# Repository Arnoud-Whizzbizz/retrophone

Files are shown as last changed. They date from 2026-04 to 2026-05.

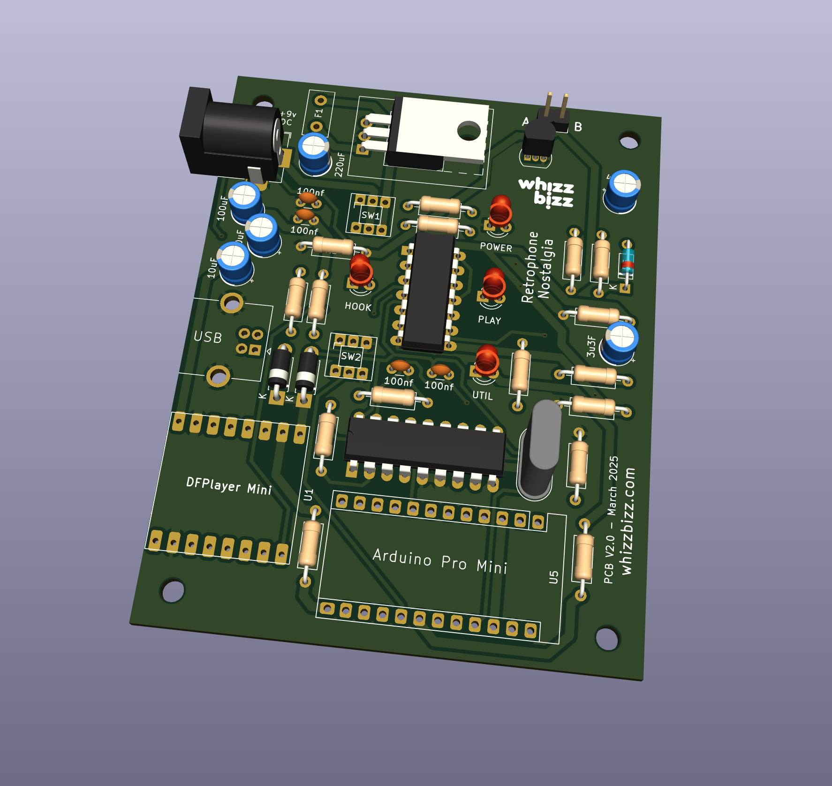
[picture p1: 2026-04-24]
Printed circuit board/pcb-render.png

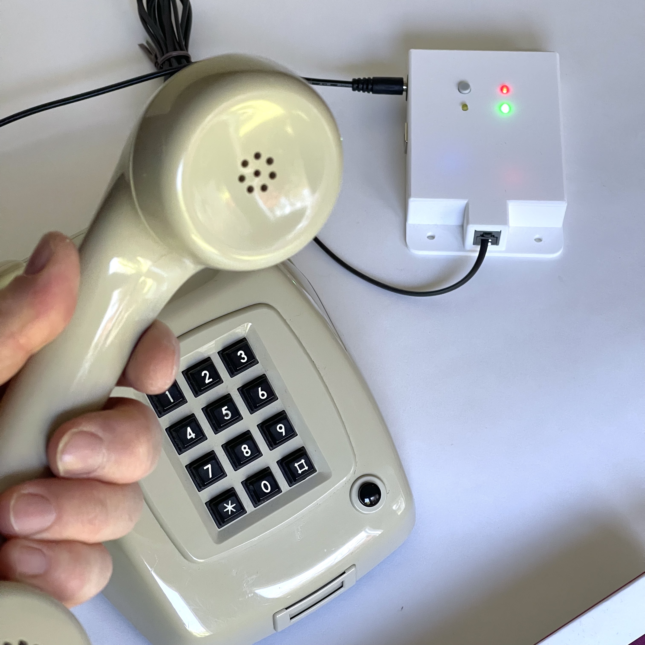
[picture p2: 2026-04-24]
Images/vintage-tone-dial-RJ11.jpeg

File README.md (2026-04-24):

the Retrophone! Use any modern or vintage telephone to play MP3s!!

This is a box that can be supplied in various versions. Any classic or modern telephone can be connected to it. The basic model is 'open-source'. The schematic, the software, the design of the printed circuit board and the 3D design of the box can be used by anyone with some technical knowledge to build one themselves. This switchboard can be used with dial telephones as well as with the more modern push-button (DTMF, such as the T65 TDK) telephones.

Just plug in your phone and you're done. A hundred of different music or audio fragments can be played with it. The phone actually waits for the dialing of a complete phone number and bases on which fragment is played.

Getting started and manual on https://www.whizzbizz.com/en/mp3-player-switchboard
DIY building instructions on https://www.whizzbizz.com/en/retro-phone-mp3-player
More about FTDI programming: https://www.whizzbizz.com/en/retrophone-ftdi-programming

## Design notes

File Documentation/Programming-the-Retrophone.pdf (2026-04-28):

Programming the Retrophone – [v1.2 april 2026]

Programming the microcontroller

The Retrophone is built around a microcontroller (Arduino Pro Mini, 5 volts, 16 MHz). In addition to the schematic, the 3D design of the enclosure, and the PCB layout, the firmware is also open-source and can be found on the project page for the design on GitHub.

GitHub: https://github.com/Arnoud-Whizzbizz/retrophone

Anyone who has built the Retrophone themselves will first need to install the firmware—the program stored in the microcontroller—before the circuit can be put into use. However, anyone who wishes to modify the existing functionality and has sufficient technical knowledge can also (re)program the Retrophone. For software development, the Arduino IDE development environment is the obvious choice. It can be downloaded for free from the official Arduino website.

Arduino IDE: https://docs.arduino.cc/software/ide/

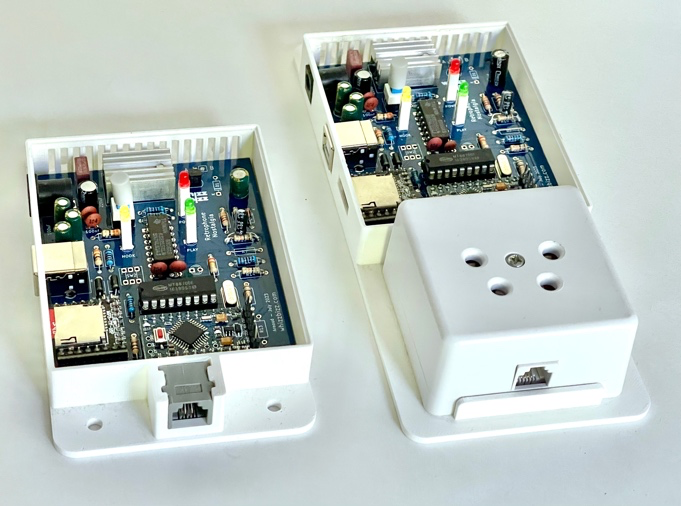
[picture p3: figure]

To program or reprogram the Arduino Pro Mini, you must open the case and connect a suitable programmer with a USB connection to the six exposed pins on the short side of the microcontroller board. A so-called FTDI programmer is used for this purpose, and various inexpensive versions are available for purchase online. The photos below show two versions with an FT232RL FTDI chip.

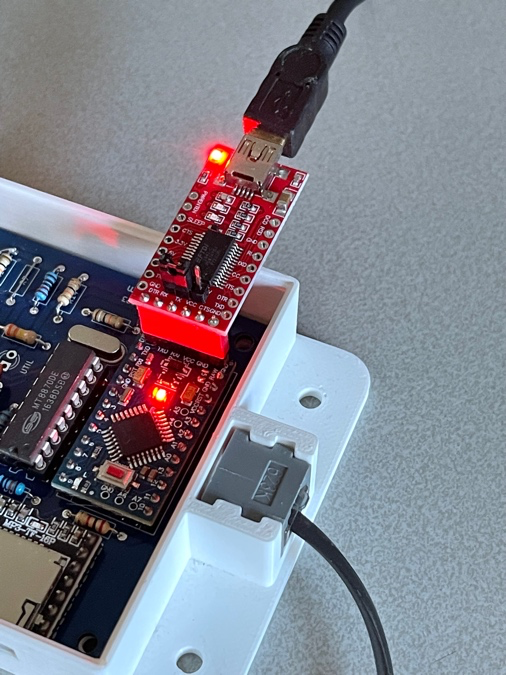
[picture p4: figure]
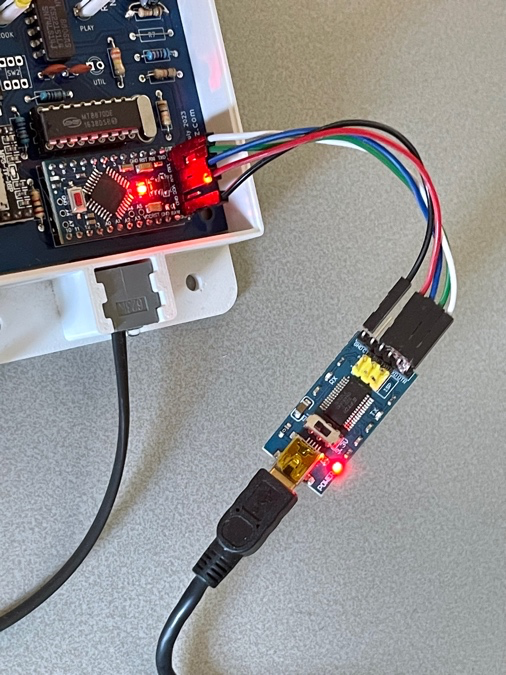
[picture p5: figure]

As soon as the FTDI board is connected, it will appear on your computer as a USB interface, and the software loaded or developed in the Arduino IDE can be uploaded to the Retrophone’s microcontroller.

A detailed description of programming the ATmega328P chip in the Arduino Pro Mini is, of course, beyond the scope of this document. Fortunately, there is a wealth of information available online about
programming an Arduino microcontroller using the Arduino IDE.

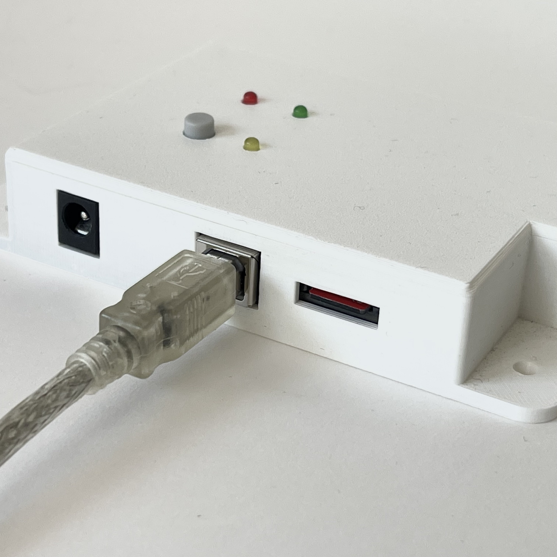
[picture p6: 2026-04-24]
Images/USB-B-connection.jpeg

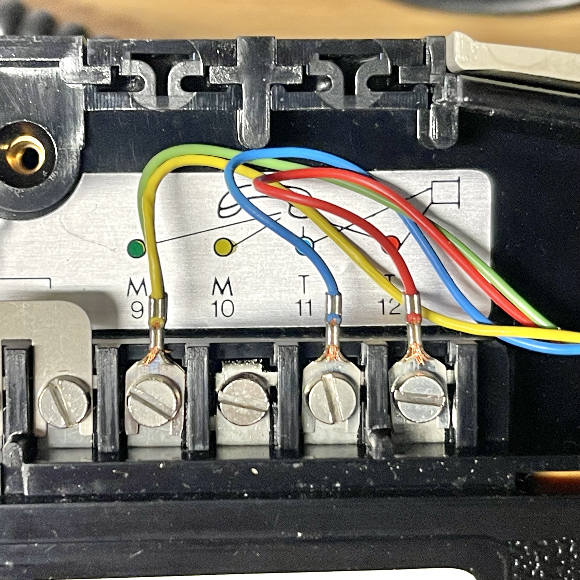
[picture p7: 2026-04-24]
Images/combine-9-and-10.jpeg

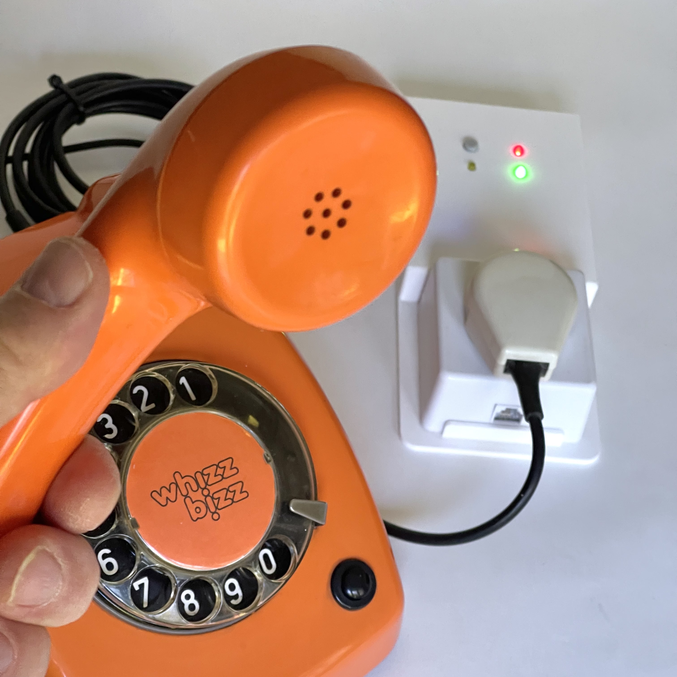
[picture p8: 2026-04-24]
Images/vintage-rotary-dial-PTT.jpeg

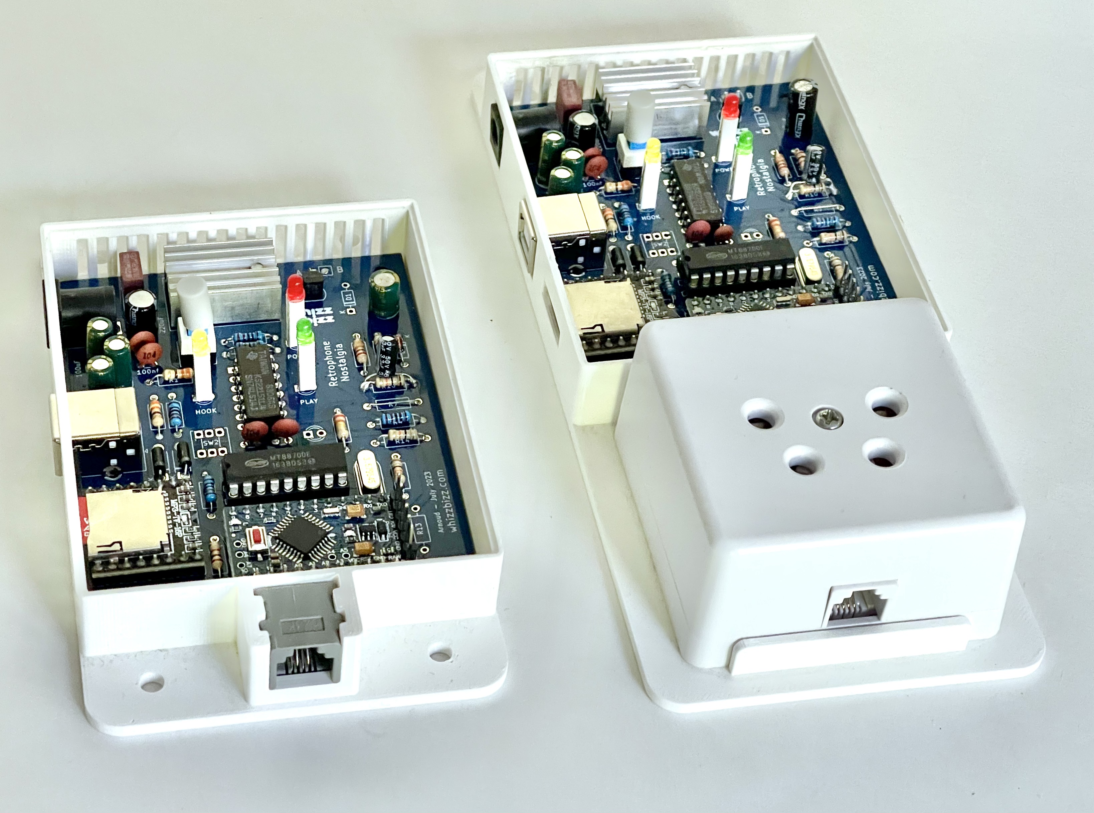
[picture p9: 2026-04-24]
Images/both-models.jpeg

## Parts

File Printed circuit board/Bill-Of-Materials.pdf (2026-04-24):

Bill of materials IDK+(TDK) 'Retrophone' Rev1 (july 2023) & Rev2 (march 2025) - Arnoud Whizzbizz.com

Designator | Package | Quantity Designation | Comment, Link
R12,R5 | Axial DIN0207 L6.3mm P10.16mm | 2 | 1K
R3 | Axial DIN0207 L6.3mm P10.16mm | 1 | 330
R17,R16,R8 | Axial DIN0207 L6.3mm P10.16mm | 3 | 2K2
D3,D8,D7,D6 | LED_D3.0mm | 4 | LED 3mm
U5 | Arduino_Pro_Mini | 1 | Pro Mini 328 | 35 pin Arduino Pro Mini module with FTDI programming port
SW1 | SW_Push_2P2T_7x7 | 1 | POWER | 7x7mm DPDT with lock - Take care of mounting orientation!
U1 | DFPlayer_Mini | 1 | DFPlayerMini | DFPlayer Mini module. Use MP3-TF-16P with the blue LED!
CP2,CP1 | CP_Radial_D5.0mm_P2.50mm | 2 | 10uF
C3,C5 | C_Disc_D3.0mm_W1.6mm_P2.50mm | 4 | 100nf
F1 | Fuse_8.5x4 | 1 | 500mA
U3 | TO-220-3_Horizontal_TabUp_Heatsink | 1 | LM7805_TO220 | LM7805 with alu heatsink 22x15 mm, 10mm high for TO-220 package
Q1 | TO-92_Inline | 1 | BC547
C2 | CP_Radial_D5.0mm_P2.50mm | 1 | 220uF
U2 | DIP-14_W7.62mm_LongPads | 1 | 74LS14 | DIP14 TTL Hex Schmitt Trigger Inverters
D2,D4 | D_DO-41_SOD81_P7.62mm_Horizontal | 2 | 1N5817 | Schottky diodes
C7 | CP_Radial_D5.0mm_P2.50mm | 1 | 470uF
C8 | CP_Radial_D5.0mm_P2.50mm | 1 | 3u3F
C4 | CP_Radial_D5.0mm_P2.50mm | 1 | 100uF
R10 | Axial DIN0207 L6.3mm P10.16mm | 1 | 10K
R14,R15 | Axial DIN0207 L6.3mm P10.16mm | 2 | 10K
R2 | Axial DIN0207 L6.3mm P10.16mm | 1 | 27K
R4 | Axial DIN0207 L6.3mm P10.16mm | 1 | 2K2
R1 | Axial DIN0207 L6.3mm P10.16mm | 1 | 330
D5 | D_DO-35_SOD27_P7.62mm_Horizontal | 1 | 1N4148 | Rotated cathode designator on silk screen of pcb Rev1! Rotate 180 degrees!
J1 | BarrelJack_Horizontal | 1 | Barrel_Jack_Switch | DC input for 9v adaptor (5.5mm with 2.5mm pin)
J3 | PinHeader_1x02_P2.54mm_Vertical | 1 | Phone | 2-pin header for connecting a/b of the phone connector
D1 | D_DO-35_SOD27_P7.62mm_Horizontal | 1 | 1N4001 | Rotated cathode designator on silk screen of pcb Rev1! Rotate 180 degrees!
J2 | USB_B_OST_USB-B1HSxx_Horizontal | 1 | USB_B | USB-B type pcb connector (optional)
R7 | Wire bridge (Resitor has been removed) | 1 | Wire | Only on pcb Rev1 (july 2023), was corrected in pcb Rev2 (march 2025)

Optional momentary-action switch SW2 Util/Config button with LED D6
Designator | Package | Quantity Designation | Comment, Link
SW2 | SW_Push_2P2T_7x7 | 1 | UTIL/CONFIG | 7x7mm DPDT without lock - Take care of mounting orientation!
R13 | Axial DIN0207 L6.3mm P10.16mm | 4 | 2K2
D6 | LED_D3.0mm | 4 | LED 3mm | Util/Config LED

Optional DTMF ('TDK') decoding (tone dialing and modern phones)
Designator | Package | Quantity Designation | Comment, Link
Y1 | Crystal_HC18-U_Vertical | 1 | 3.579545 MHz | May be classic high model, or low passive resonator model
U4 | DIP-18_W7.62mm | 1 | MT8870 | DIP18 version of the MT8870 or MV8870 DTMF decoder
C1, C6 | C_Disc_D3.0mm_W1.6mm_P2.50mm | 4 | 100nf
R6, R9 | Axial DIN0207 L6.3mm P10.16mm | 2 | 100K
R11 | Axial DIN0207 L6.3mm P10.16mm | 1 | 330K

Casing, 3D-prints, additional assembly materials
Designator | Package | Quantity Designation | Comment, Link
PCB | Printed Circuit Board | 1 | Rev1 or Rev2 | Printed Circuit Board (Gerber files on GitHub)
3DCASE | 3D printed case (either for RJ11 or Dutch PTT connector) | 1 | | STL files of (wall-)case and lid on GitHub
HTSNK | Heatsink for TO-220 | 1 | | Aluminum heatsink 22x15 mm, 10mm high for TO-220
SPACER | Aluminum washer spacer | 1 | 4mm thick | Used for mounting the heatsink and 7805 regulator
SCREW1 | M3 bolt | 2 | M3 x 12mm | M3 bolt for fixing the heatsink and 7805 regulator
WASH1 | M3 washer | 2 | | Steel washer M3 to assemble heatsink and 7805 regulator
SDCARD | SD-Card for the DFPlayer Mini | 1 | | >=2GB is recommended
BTNCAP | Tactile Push Button Switch Cap 10mm | 2 | | Tactile Push Button Switch Cap 10mm
SCREW2 | 3 x 12mm Countersunk head screw | 4 | | Used to fix the lid and secure the pcb in the case
SCREW3 | M3 Bolt | 2 | M3 x 12mm | M3 bolt for fixing the classic Dutch PTT phone wall box
WASH2 | M3 Washer | 2 | M3 | Steel washer M3 to firmly assemble the wall box
M3NUT | M3 Nut | 2 | M3 | DIN934 M3 Hex Nut Metric Thread
WIRE | Small length of colored (red/blue) electric wire | 2 | 100mm | General purpose 24 AWG electric wire for connecting a/b of phone
PHONE CONN | Landline wall box for connecting a Dutch PTT phone | 1 | | Dutch: Q-Link telefoon contactdoos opbouw (Art.Nr. 00.133.44)
| OR: Wired 6P4C RJ11/12 chassis connector female | 1 | | Use only green and red wires to connect to 'A' and 'B' inputs
POWER | AC/DC 9V 2A Switching Power Supply Adapter | 1 | | AC/DC 9V 2A Switching Power Supply Adapter
| IDK "Impuls Druk kiezen": Pulses during the dialing
| TDK "Toon Druktoets Keuze": Tones during the dialing

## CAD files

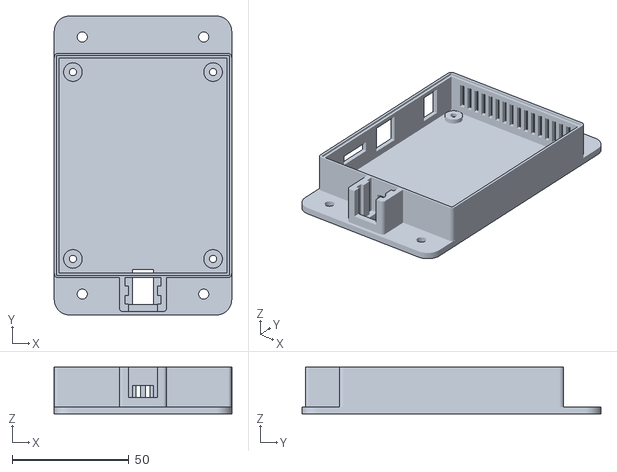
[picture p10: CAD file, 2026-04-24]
3D/RJ11-port-case.stl
76.0 x 128.0 x 20.0

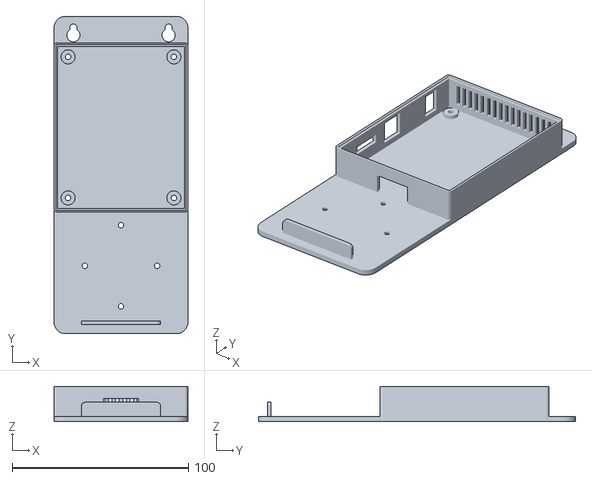
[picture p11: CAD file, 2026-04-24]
3D/wall-case.stl
76.0 x 180.0 x 20.0

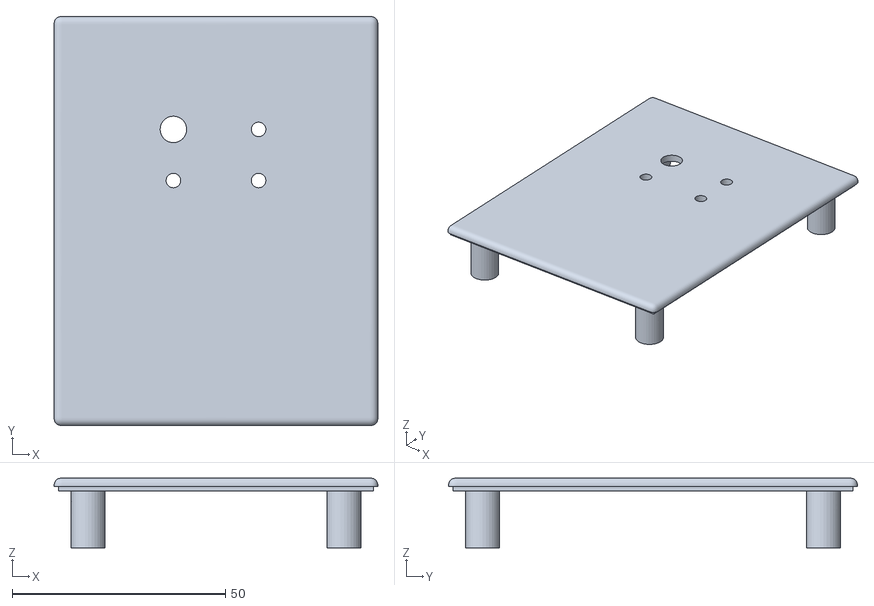
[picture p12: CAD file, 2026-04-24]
3D/lid-flat-basic-holes.stl
76.0 x 96.0 x 16.4

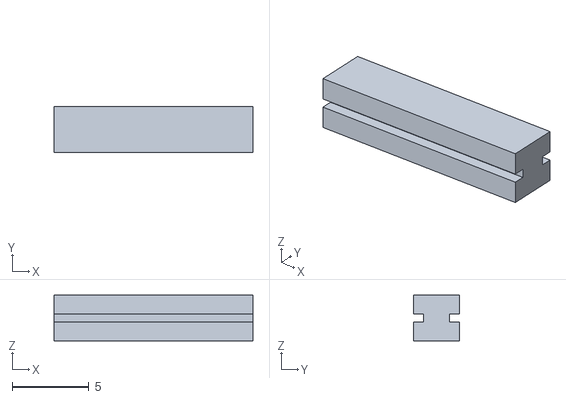
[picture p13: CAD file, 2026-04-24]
3D/LED_raiser.stl
13.0 x 3.00 x 3.00

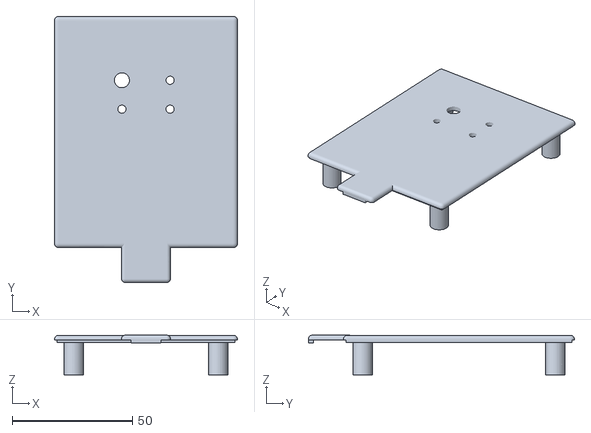
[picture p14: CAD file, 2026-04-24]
3D/lid-flat-basic-holes-RJ11-lip.stl
76.0 x 110.5 x 16.4

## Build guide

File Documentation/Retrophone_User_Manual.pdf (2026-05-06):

Retrophone User Manual – [v1.2 april 2026]

What is the Retrophone?

The Retrophone is a “telephone switchboard” to which you can connect a classic “landline” telephone. When you pick up the receiver, you will hear a dial tone. After dialing a phone number, one of the hundred audio clips on the memory card will play. With the dialed numbers, any of the up to ten audio clips in up to ten folders on the memory card can be played.

No modifications are required for the phone to be used. Depending on the Retrophone model, rotary-dial phones (IDK) and/or push-button phones (TDK) can be used. Depending on the version, a classic phone can be connected using the traditional Dutch PTT plug, while a modern phone can be connected using a modular RJ11 plug.

Get started

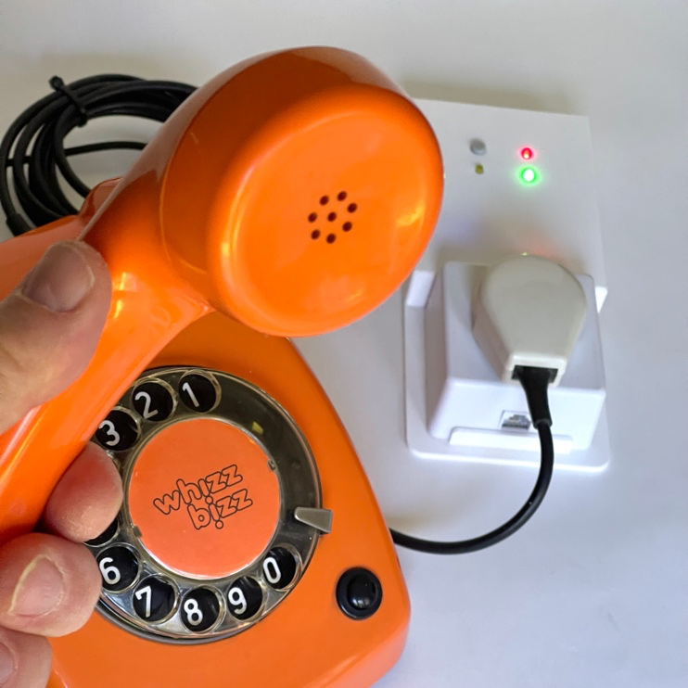
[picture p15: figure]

The Retrophone is powered by a 9-volt DC power adapter. Only models with a 5.5 mm pin diameter and a 2.5 mm hole (for the positive terminal) can be used. If the power adapter is not included, please check that your power adapter is compatible before using it! The technical specifications are listed on the back of the Retrophone.

The power adapter is connected to the side of the Retrophone. Here you will also find (optionally) the USB port for accessing the memory card, and a slot for removing the memory card. Detailed information about the memory card’s file structure can be found later in this manual.

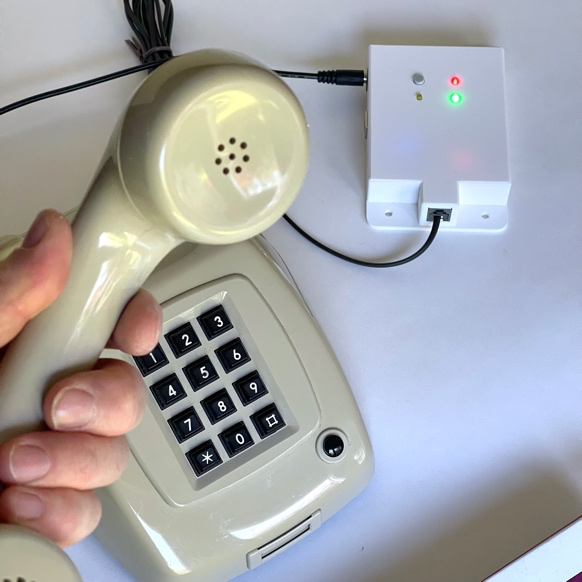
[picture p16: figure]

Turning on the Retrophone

Once the power adapter and phone are connected, and a microSD memory card is inserted, the Retrophone can be turned on using the power switch on the front.

The colored lights (LEDs) will all light up simultaneously for a moment. When only the red light next to the power switch is lit, the Retrophone is ready for use.

Preparing the memory card

The Retrophone includes an audio player (MP3-TF-16P, also known as the DFPlayer Mini) that allows audio files to be played directly from a microSD card (also known as a TF card). This memory card must be formatted with the MS-DOS or ExFAT file system. Memory cards with a maximum storage capacity of 32 GB can be used. However, for most applications, microSD cards with a smaller storage capacity (e.g., 8 GB) are usually more than sufficient.

File organization and playback principles

The file format and naming convention for the audio files on the memory card are straightforward. In addition to a few audio files at the root level, the memory card may contain up to ten numbered folders (“01”, “02”, “03” … through “10”). Each folder may contain up to 10 audio clips. Since the player isn’t very sophisticated, it’s advisable to use numbered filenames for these clips as well (‘001.WAV’, ‘002.WAV’ … through 010.WAV). This way, the folders can hold up to 100 audio clips.

From the root directory of the microSD card, only the first two audio files found are used. The first is played when the phone’s receiver is picked up. This is usually the dial tone that should be heard in the receiver while dialing the phone number, though it can also be a spoken instruction or similar. The second audio clip, usually the “busy tone,” is played if, based on the dialed phone number, no audio clip can be found. In principle, this is only possible if there are fewer than 100 playable clips in the folders on the microSD card.

The link between the phone number dialed by the user on the connected phone and the audio clip that is ultimately played is very simple: the very first digit dialed determines the folder (1 for folder ‘01’, 2 for folder ‘02’, etc.), and the very last digit dialed in the sequence determines the audio clip to be played within that folder (1 for ‘001. WAV’, 2 for ‘002.WAV’, etc.). If only one number is dialed within the maximum sequence number timeout (2.5 sec.) of the dialing phase, this is the clip number in the first folder ‘01’.

Audio encoding of the audio files

In principle, the Retrophone’s player can play audio files in WMV/WMA (WAV) and MP3 formats. When encoding to MP3, a ‘constant bitrate’ (CBR) of 128 kbps gives the best results. However, in practice, MP3 files in the numbered folders are sometimes not recognised properly. The dial tone and busy tone, the files for which are stored on the root level of the memory card, cause fewer problems in this regard.

The WMV/WMA audio format is compressed and requires decompression during playback by the audio player. As these are often short clips in practice, it is recommended to choose the most standardised (uncompressed) WAV variant. Although this results in slightly larger audio files, they offer significantly better playback quality. Encode the files at a maximum of 32 kHz, 16-bit in mono (stereo is, of course, pointless for this application) for the best results. Theoretically, sampling rates of 44.1 kHz and even 48 kHz at 24-bit resolution are possible, but the resulting improvement in quality is far beyond the technical capabilities of a mobile phone speaker.

The best audio converters for both Windows and Mac are fre:ac (free and open-source), MediaHuman Audio Converter (free, user-friendly), and Switch Audio Converter (paid, but very versatile). These programs support formats such as MP3, WAV, FLAC, and M4A, and offer batch conversion, making it easy to convert multiple files to a different audio format all at once.

Accessing the files on the memory card using your computer

To back up the current contents of the memory card or load a completely new set of audio clips, you must first make the memory card accessible in your computer’s file explorer (Windows: File Explorer, Mac: Finder). To do this, first turn off the Retrophone using the power button on the front panel. You can also unplug the 9-volt AC adapter. Make sure the red LED is off.

To access the files on the memory card using your computer, we
recommend removing the memory card from the Retrophone’s slot. To

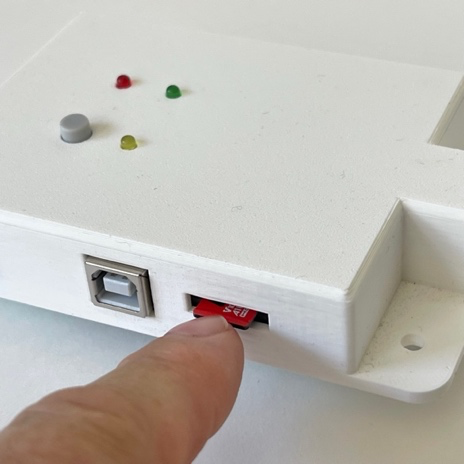
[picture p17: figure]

do this, gently push the SD card slightly further into the slot from the side of the case. When you release the card, a spring mechanism will cause it to pop out slightly, making it easy to remove from the slot. Some computers have a slot where the microSD card can be inserted directly. However, it is also always possible to temporarily place the memory card in a card adapter—such as a card reader that looks like a USB flash drive or a larger SD card—to make it accessible on your computer. When you are finished, you can carefully push the memory card back into the slot. The Retrophone is then ready for use again.

If your Retrophone has a square USB-B port (this does not apply to all
models), you can use a USB-A (standard flat plug) to USB-B (square) cable
to connect the Retrophone to your computer. The advantage of this is that
you don’t need to use a microSD card adapter, but keep in mind that this connection isn’t as fast as the one described above. And remember that when you’re done and want to use the Retrophone again, you’ll need to disconnect the USB cable. As long as the microSD card is “claimed” by your computer, the Retrophone cannot play audio files from it!

Edit or add audio clips to the memory card

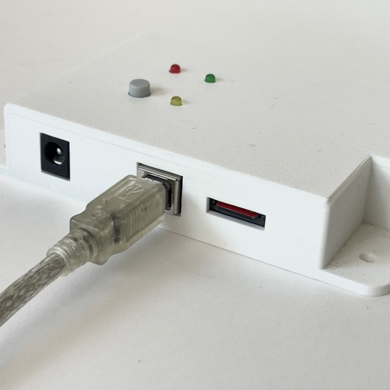
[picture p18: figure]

The Retrophone’s audio player has very limited “intelligence.” The player selects tracks based entirely on the order of the files on the microSD card. The (sequentially numbered) file names, which can be used on your computer to sort the files in a specific order, are ignored! Only the order in which the files were written from your computer to the microSD card determines the sequence number assigned by the player.

This is important to understand, because it explains why it is not possible to renumber files later in the naming scheme, or to insert files into the naming sequence on the memory card. These additional files will simply be written physically after the files already present on the memory card, regardless of the visible order based on their filenames. The underlying physical order on the microSD card will therefore differ from the folder view on your computer in those cases!

It is therefore advisable to set up (and manage and archive) the desired final file structure of the memory card in a folder on your computer’s hard drive. If you acquire a ready-made Retrophone that includes a memory card, you should make a complete copy of this memory card. In a separate folder (possibly cloned from the original), you can then create your own set of audio clips, copying the folder structure (and, if applicable, the dial tone and busy tone). By managing the various memory card “contents” on your computer, you can easily switch between the different collections of clips for various applications of the Retrophone.

Copying a new set of audio clips to the memory card

Once the new set of audio clips has been compiled on the computer, it can be written to an empty microSD card in one go.

Note: If you are using a Mac, “hidden” files will have been written to the microSD card that may confuse the player. It is important that these hidden “AppleDouble” metadata files (.DS_Store, etc.) are deleted. You can do this easily by opening a macOS Terminal and navigating to the mounted memory card (e.g., /Volumes/RETROPHONE) on your Mac.

If you have copied the bash script ‘prepare-card.sh’ to the microSD card, you can use it for this purpose. This script also automatically renames the audio files in all folders to sequential numbers. You can run the script in the macOS Terminal using the command ./prepare-card.sh

It is also possible to use the standard command `dot_clean` (dot_clean -m /Volumes/RETROPHONE) available on your Mac in the macOS Terminal for cleaning up.

The final step is to “eject” the microSD card from your computer or remove it from the card adapter. After disconnecting the USB cable (method 2 above) or reinserting the memory card into the Retrophone’s slot (method 1 above), you can turn the Retrophone back on and check whether all audio clips are accessible and playable.

For perfectionists with a Dutch T65 phone

Just like with traditional telephones of the past, some “crosstalk” from the microphone (which is not used by the Retrophone) in the handset may be heard through the speaker. Anyone who blows into the handset will hear this sound through the speaker. If you find this annoying, you can simply
remove the microphone from the mouthpiece of the handset (unscrew the
bottom cap on the handset).

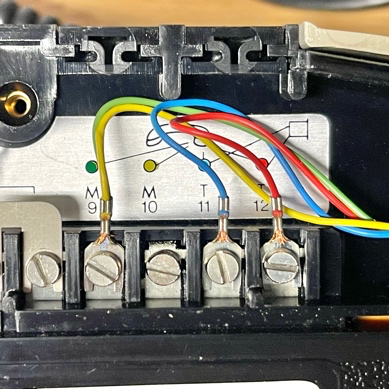
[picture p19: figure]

If you want to solve this in a technically neat way on the commonly used Dutch T65 telephone, you can open the cover on the bottom of the phone and connect the wire under terminal 10 (yellow) to the wire under terminal 9 (green), thereby bypassing the microphone in the handset. However, the Retrophone works perfectly well even without these modifications.

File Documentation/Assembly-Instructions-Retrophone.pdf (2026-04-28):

Assembly Instructions – Retrophone – Whizzbizz.com

This document provides some tips for anyone who wants to build the “Retrophone” telephone jukebox for classic phones themselves. A complete list of all necessary parts, the 3D print files, and basic firmware for the Arduino Pro Mini used in the design are open-sourced and available at https://github.com/Arnoud-Whizzbizz/retrophone (https://github.com/Arnoud-Whizzbizz/retrophone)

Everyone is strongly encouraged to use the design for their own experiments. The electronic design and software are released under the GPL-2.0 license. (https://www.gnu.org/licenses/old-licenses/gpl-2.0.html) It is not permitted to use the designs or firmware for commercial purposes without permission.

Fully assembled and tested Retrophones (including a telephone, if desired) are available as custom-made units upon request. For professional custom projects, a modular system is used that can be triggered by external sensors, control door openers and relays, ring the bell in the telephone, etc. Please contact us via the contact form on the website whizzbizz.com if you are looking for ready-made solutions for, for example, your escape room, exhibition, or art project.

I do not supply individual parts, kits, etc. However, a few remaining units of the first version of the circuit boards (marked “July 2023”) are available upon request for those who wish to build a Retrophone themselves immediately, without first having to have the circuit boards manufactured in a larger batch. Please submit your request or question via the contact form on the website whizzbizz.com

RJ11 or PTT Plug

There are two versions of the Retrophone available.
If you want to be able to connect a classic Dutch telephone (such as the T65) immediately without any modifications, choose the model with the integrated PTT socket. The housing can be printed using the 3D files ‘wall-case.stl’ and ‘lid-flat-basic-holes.stl’.

The Q-Link surface-mount telephone jack (Part No. 00.133.44) available in the Netherlands also features an RJ11 port for modern or foreign telephones.

If you only need an RJ11 connector on the
Retrophone, you can choose to print the housing (or

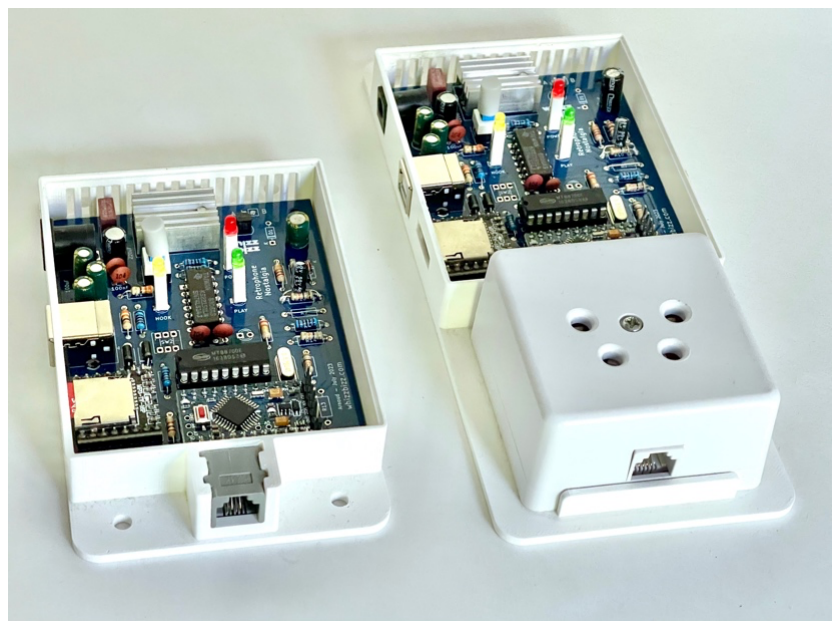
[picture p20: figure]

have it printed) using the 3D print files “RJ11-port-case.stl” and “lid-flat-basic-holes-RJ11-lip.stl”.

Touch-tone dialing and/or tone dialing

The Retrophone can be used with both traditional rotary-dial phones (such as the classic T65) and more modern push-button phones (such as the T65-TDK).

Traditionally, the dialing process for a phone with a classic rotary dial is referred to as “Impulse-Dialing” (IDK). Push-button phones are devices with so-called “Tone-Dialing” (TDK). These devices use tones instead of pulses. To use these devices, the Retrophone must be equipped with a so-called Dual-Tone Multi-Frequency (DTMF) decoder.

However, this is not necessary. If the Retrophone is used exclusively with a rotary-dial telephone, components U4 (the MT8870 DTMF decoder), crystal Y1, capacitors C1 and C6, and resistors R6, R9, and R11 can be omitted.

Additional momentary switch

The SW2 and LED D6 (with series resistor R13) are also optional. They do not need to be included in the standard version of the Retrophone.

This additional “configuration pushbutton” is a potential future expansion and is not currently supported in the standard firmware. For specific customization, this pushbutton can, for example, be used to add additional functionality to the basic functions.

Building instructions

1. Before soldering the Arduino Pro Mini board to the main PCB, make sure to install a 6-pin female header on the FTDI side for programming. This interface does not make any further contact with the PCB. For programming, you can use, for example, an FT232RL FTDI programmer board equipped with a 6-pin female connector.
2. Not all pins on the MP3 player and Arduino Pro Mini need to be soldered. Dots on the bottom silk screen indicate the pads that must be soldered (in version “PCB V2.0 - March 2025” of this board).
3. Mount the 7805CV voltage regulator with a small heat sink using an M3 12mm screw (flat head on the PCB side) and a 4mm metal (aluminum) spacer. Apply a small amount of thermal paste if necessary. Mount first, then solder.
4. The 7x7mm on/off switch and the momentary pushbutton must be mounted with the “double marking” (2 black lines visible through the white cover) facing to the right.
5. The LEDs must be mounted with the flattened side (cathode to ground) on the left.

The so-called Gerber files on GitHub have now been updated and include the “March 2025” designation, but if you are using PCB version 1 with the “July 2023” designation, there are a few things you need to keep in mind:

- NOTE: D1 was unnecessary and can be omitted.
- NOTE: Due to an error in the footprint printing, D5 must be mounted reversed!
- NOTE: A 3µF electrolytic capacitor must be soldered over R10 (10KΩ).
- NOTE: R7 was unnecessary and has been omitted; it must be replaced with a wire jumper.

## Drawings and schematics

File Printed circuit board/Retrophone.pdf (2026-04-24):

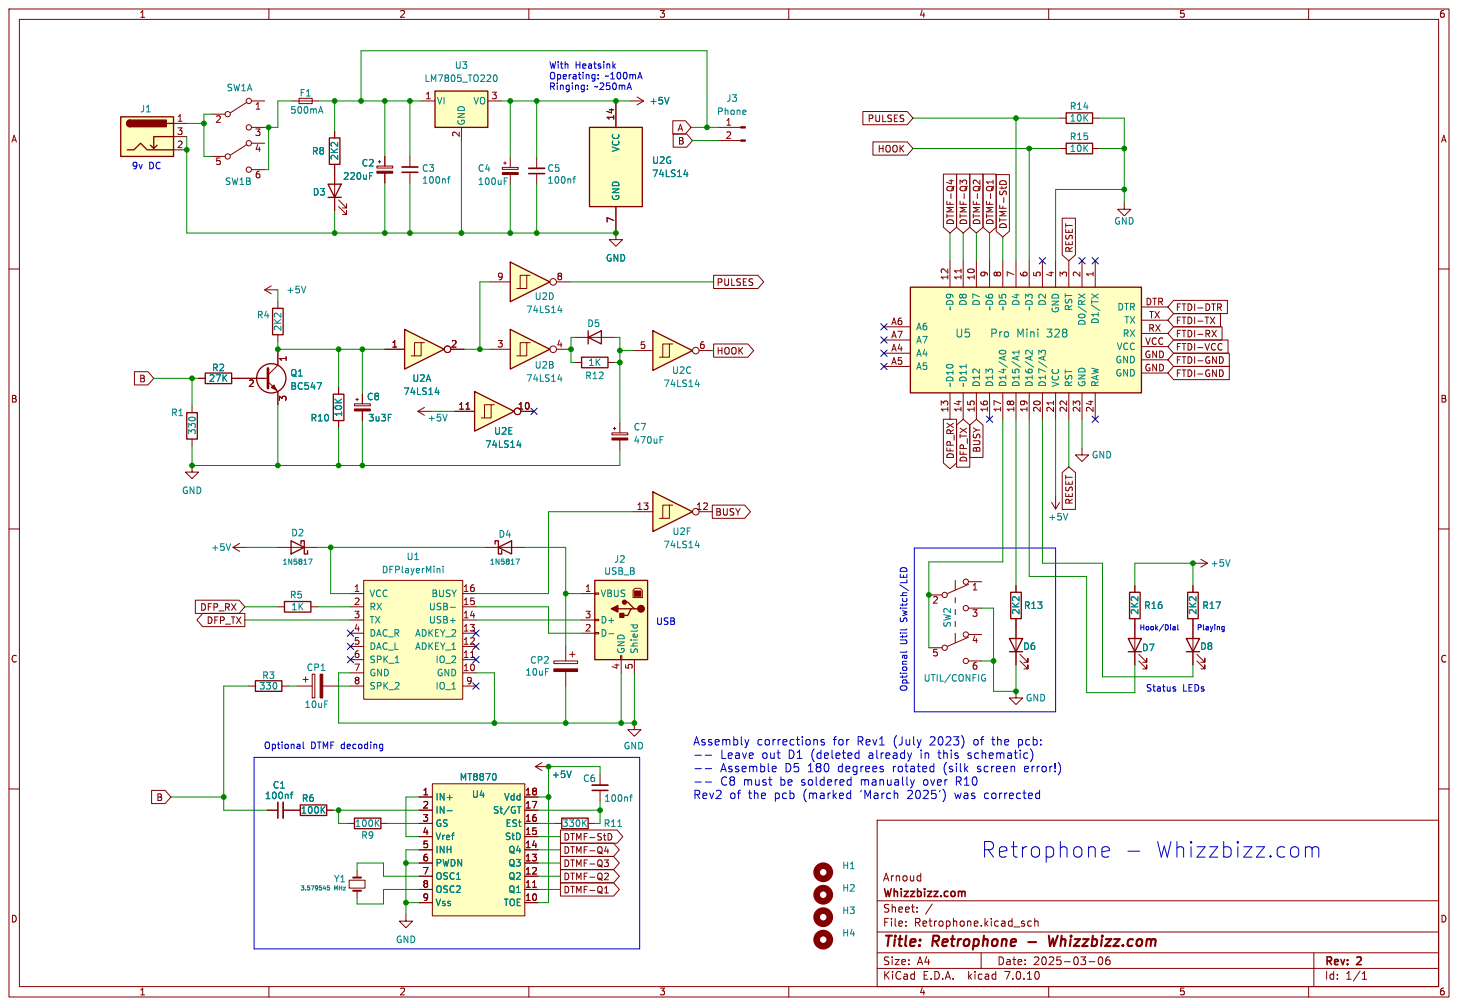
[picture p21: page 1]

FTDI-TX DTMF-StD DTMF-Q1

9 A4 A4 A5 A5 A6 A6 A7 A7 DTR DTR GND GND GND GND

2 D17/A3 20 VCC 21 RST 22 GND 23 RAW 24 RST

Arnoud
File: Retrophone.kicad_sch Sheet: / Whizzbizz.com

Id: 1/1 Title: Retrophone - Whizzbizz.com

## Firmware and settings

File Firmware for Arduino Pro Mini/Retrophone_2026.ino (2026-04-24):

// Whizzbizz.com - Arnoud van Delden - July 2023 ~ July 2025 ~ April 2026
//
// This sketch is a further development of my project found at https://www.whizzbizz.com/en/gpo746-t65-rotary-dial-phone-mp3-wav-player
// that needed modification of a Dutch PTT T65 rotary dial phone or a contemporary retro-model GPO746 dial telephone
//
// Waits for hook switch signal and then reads the number from the rotary dial, or decodes the DTMF tones of push button (TDK) phones.
// The 'flash'-button on the telephone, or the generic 'function' button on the pcb may be used to make a direct random selection from all samples, 
// otherwise the first (or only) number determines the subdir/bank to be used (each bank has 10 WAVs) and the last number dialed the WAV within this subdirectory/bank.
// Samples are played through DFPlayer (Mini MP3 Player) controlled over SoftwareSerial with RX=10 and TX=11
//
// Expects a SD-card with the correct directory structure of ten banks/subdirs of ten WAVs each
// The bank/folder/subdir '00' contains the sounds that are played when only one number was dialed
// Otherwise first number is the bank/subdir, last number dialed the sound that is to be played
//
// Important: the player module can only play constant bitrate (CBR) MP3's, 128 kbs is preferred
// Convert and prepare MP3's accordingly with e.g fre:ac on Windows, or Switch when you're on a Mac
//
// First found WAV/MP3 in the root of the SD card is used as dial tone
// Second found WAV/MP2 in the root of the SD card is used as busy tone
//
// The whole system to determine if the audio player is 'busy' was stripped. In the former version there was a DO_ANALOG_BUSY define to switch this 
// to an analog input of the ATMega328 because the level from pin 12 of the 74LS14 did not seem apropriate. But later this was okay, and further more:
// whats the use of knowing (on an hardware level) that the audio player is 'busy'. It is busy right away by playing the dial tone...
//
// Findings / Pitfalls
// -- The DfPlayer modules marked with 'HW247A' (red LED) do NOT have the functions readFileCountsInFolder() and readFolderCounts() implemented! 
//    It is not possible to count files in folders with these! Beter use the ones marked MP3-TF-16P with the blue LED!
// -- Usage of and/or define pinMode of A7 will cause the DfPlayer (both models) to freeze. Not solved yet, use another input!
//

#include "SoftwareSerial.h"
#include "DFRobotDFPlayerMini.h"

//#define DEBUG          // Outcomment for production...

#define DO_FILECHECK     // Enable if busy tone must be player when audio file is not found. This must be audio fragment 2 on the SD-card.

// #define DO_FLASH      // Only useful if green ground wire is on clamp 2 of the T65 (or clamp 13 of the SSB 51553) and in the RJ9 cable
//#define DO_ANALOG_BUSY // Read MP3 player 'busy' not digtally from D12 but analog from A6

#define BlinkTime 10000

#define input_hook     3 // Receiver picked up: hook off (HIGH active)
#define input_pulse    4 // Rotary dial pulses (HIGH active)

#define input_std      5 // DTMF StD, DTMF tone stable
#define input_q1       6 // DTMF Q1
#define input_q2       7 // DTMF Q2
#define input_q3       8 // DTMF Q3
#define input_q4       9 // DTMF Q4

// These two are optional, may not be placed on the pcb (and R13 left out)
#define set_button    14 // Util/Config button (HIGH active)
#define led_config    15 // Util/Config LED: used to flash pulses or decoded DTMF (HIGH active)

// These are always there...
#define led_dial_play 16 // Yellow Hook/Dial LED: lit on hook-off, flashes when dialing (LOW active)
#define led_playing   17 // Green LED: lit when music is played (LOW active)

#ifdef DO_FLASH
// A (yet) unsolved mystery: using analog input A7 will HANG the MP3Player! Using D13 instead...
#define input_flash   13 // Green ground wire in phone must be on clamp 2 (for T65) or clamp 13 (SSB 51553) and in the RJ9 cable
#endif

// Busy/Playing signal from DFPlayer Mini (digital HIGH is active) is NOT used/read anymore...
// #define MONITOR_BUSY 
#ifdef MONITOR_BUSY
#define input_busy 12
#endif

unsigned long debounceTimeHook  = 0; // Debounce time for this button/pin...
unsigned long debounceTimePulse = 0; // Debounce time for this button/pin...
unsigned long dialingTimeout = 0;     // To keep track of dialing time out...
unsigned long debounceDelay = 50;      // Global debounce time...

bool hookUp = false;
bool dialing = false;
bool processNumber = false;
bool pulseCounting = false;
bool playerActive = false;
uint8_t dtmfTone;

int hookState;
int pulseState;
int setState;
int lastHookState = LOW;
int lastGpioStatePulse = HIGH;
int lastSetButtonState = HIGH;
int lastNumberDialed = 0;
int nrsDialed = 0;
int pulseCount = 0;
int blinkCount = 0; // For the blinking LED...

int gpioStatePulse;
int hookSwitchState;
int setButtonState;

#ifdef DO_FILECHECK
int firstFolderNr = -1;
uint8_t nrFilesInFolder[20]; // Limited to max 10
int nrFiles;
int nrFolders;
uint8_t folderNr;
#endif

int bankNr = 0;
int songNr = 0;

SoftwareSerial mySoftwareSerial(11, 10); // RX, TX
DFRobotDFPlayerMini myDFPlayer;
uint8_t playerError;
void printDetail(uint8_t type, int value);

void setup() {
  mySoftwareSerial.begin(9600);
  Serial.begin(38400);

  // A (yet) unsolved mystery: using analog input A7 will HANG the MP3Player! Using D13 instead...
  pinMode(input_std, INPUT);
  pinMode(input_q1, INPUT);
  pinMode(input_q2, INPUT);
  pinMode(input_q3, INPUT);
  pinMode(input_q4, INPUT);
  #ifdef MONITOR_BUSY
    pinMode(input_busy, INPUT);
  #endif
  pinMode(input_pulse, INPUT);
  pinMode(input_hook, INPUT);
  #ifdef DO_FLASH
    pinMode(input_flash, INPUT); 
  #endif

  pinMode(led_config, OUTPUT);
  pinMode(led_dial_play, OUTPUT);
  pinMode(led_playing, OUTPUT);

  #ifdef DEBUG
    Serial.println(F("Retrophone Basic 2026"));
    Serial.println(F("Initializing DFPlayer..."));
  #endif
  while (!myDFPlayer.begin(mySoftwareSerial, /*isACK = */true, /*doReset = */true)) {  //Use serial to communicate with mp3.
    #ifdef DEBUG
      Serial.println(F("MP3 Player not ready..."));
      Serial.println(F("Will try again in 1 sec..."));
    #endif
    delay(1000);
  }
  #ifdef DEBUG  
    Serial.println(F("DFPlayer Mini online"));
  #endif

  // Various MP3 player settings...
  myDFPlayer.stop();          // End any audio after soft reset...
  myDFPlayer.setTimeOut(500); //Set serial communictaion time out 500ms
  myDFPlayer.volume(30);      //Set volume value (0~30).
  myDFPlayer.EQ(DFPLAYER_EQ_NORMAL);
  myDFPlayer.outputDevice(DFPLAYER_DEVICE_SD);

  #ifdef DO_FILECHECK
    // Determine first bankNr (folder) and nr of files per (max. 10) folder...
    for (folderNr=0; folderNr<=20; folderNr++) {
      nrFiles = myDFPlayer.readFileCountsInFolder(folderNr);
      #ifdef DEBUG  
      Serial.print(F("Folder "));
      Serial.print(folderNr);
      Serial.print(F(": "));
      Serial.print(nrFiles);
      Serial.println(F(" files"));
      #endif    
      if (nrFiles>0) {
        if (firstFolderNr<0) {
          firstFolderNr = folderNr;
          #ifdef DEBUG  
          Serial.print(F("First audio folder is "));
          Serial.println(firstFolderNr);
          #endif          
        }
        nrFilesInFolder[folderNr-firstFolderNr] = nrFiles;
        if (folderNr-firstFolderNr >= 9)
          break;
      }
    }
    nrFolders = sizeof(nrFilesInFolder)/sizeof(int);
    #ifdef DEBUG  
      Serial.print(F("nrFolders="));
      Serial.println(nrFolders);
      for (folderNr=0; folderNr<10; folderNr++) {
        Serial.print(F("nrFilesInFolder["));
        Serial.print(folderNr);
        Serial.print(F("] = "));
        Serial.println(nrFilesInFolder[folderNr]);
      }
    #endif
  #endif

  // Init LEDs...
  digitalWrite(led_dial_play, HIGH); // Off!
  digitalWrite(led_playing, HIGH);  // Off!
  digitalWrite(led_config, LOW);     // Off!

  #ifdef DEBUG
    Serial.println(F("Setup done..."));
  #endif
}

void loop() {
  // Read 'Hook' state...
  hookSwitchState = digitalRead(input_hook);  
  if (hookSwitchState != lastHookState) {
    debounceTimeHook = millis();
  }
  if ((millis() - debounceTimeHook) > debounceDelay) {
    if (hookSwitchState != hookState) {
      hookState = hookSwitchState;
      if (hookState == HIGH) {
        #ifdef DEBUG
          Serial.println(F("Receiver was picked up..."));
        #endif
        hookUp = true;
        digitalWrite(led_dial_play, LOW); // Turn on LED...
        bankNr = -1;
        nrsDialed = 0;
        // Output dial tone...
        myDFPlayer.play(1);
      } else {
        #ifdef DEBUG
          Serial.println(F("Receiver is put back..."));
        #endif
        hookUp = false;
        dialing = false;
        myDFPlayer.stop(); // End dial tone...
        digitalWrite(led_dial_play, HIGH); // Turn off LED...
        digitalWrite(led_playing, HIGH);  // Turn off LED...
      }
    }
  }
  lastHookState = hookSwitchState;

  #ifdef DEBUG
  #ifdef DO_FLASH
    Serial.print("input_flash=");
    Serial.println(digitalRead(input_flash));
  #endif
  #endif

  if (hookUp) { // Only if receiver was picked up...
    if (!playerActive) { // Only decode possible BankNr and SongNr if not already playing...
      
      if (dialing == true) {
        if (blinkCount > BlinkTime) {
          blinkCount = 0;
          digitalWrite(led_dial_play, !digitalRead(led_dial_play));  // Blink the Hook/Dialing LED...
        }
        blinkCount++;
      } else {
        digitalWrite(led_dial_play, LOW); // LED is on when MP3 player is playing...
      }

      #ifdef DEBUG
      #ifdef DO_FLASH
          if (digitalRead(input_flash))
            digitalWrite(led_playing, HIGH); // led_playing LED on...
          else
            digitalWrite(led_playing, LOW);  // led_playing LED on...
      #endif
      #endif

      if (digitalRead(input_std)==HIGH) {
        if (!dialing) { // Start dial cycle...
          #ifdef DEBUG
            Serial.println(F("Dialing started..."));
          #endif
          processNumber = false;
          dialing = true;
          nrsDialed = 0;
          bankNr = -1;
          songNr = -1;
          myDFPlayer.stop(); // End dial tone...   
        }

        // Read possible DTMF...
        delay(100);
        dtmfTone = ( 0x00 | (digitalRead(input_q1) << 0) | (digitalRead(input_q2) << 1) | (digitalRead(input_q3) << 2) | (digitalRead(input_q4) << 3) );
        if (dtmfTone>10)
          dtmfTone = 10; // DTMF has codes > 10 for '*' and '#'
        lastNumberDialed = dtmfTone;

        digitalWrite(led_config, HIGH);  // Turn on Util/Config LED...
        while (digitalRead(input_std)==HIGH)
          delay(10);
        nrsDialed++;

        #ifdef DEBUG
          Serial.print(F("DTMF number ("));
          Serial.print(nrsDialed);
          Serial.print(F(") dialed: "));
          Serial.println(lastNumberDialed);
        #endif    

        if (bankNr<0) {
          bankNr = dtmfTone;
          #ifdef DEBUG
            Serial.println("bankNr: "+(String)bankNr);
          #endif    
        }
        dialingTimeout = millis(); // Keep resetting timer during dialing...

      } else { // Pulse dialing phase...

        // Read possible pulses from rotary dial...
        digitalWrite(led_config, LOW);  // Turn off Util/Config LED...

        pulseCounting = true;
        while (pulseCounting == true) {
        
          gpioStatePulse = digitalRead(input_pulse);
          if (gpioStatePulse == HIGH)
            digitalWrite(led_config, HIGH);  // Turn on Util/Config LED...
          else
            digitalWrite(led_config, LOW);  // Turn off Util/Config LED...
          if (gpioStatePulse != lastGpioStatePulse) {
            debounceTimePulse = millis();
          }
          if ((millis() - debounceTimePulse) > 20) {
            if (gpioStatePulse != pulseState) {
              pulseState = gpioStatePulse;
              if (gpioStatePulse==HIGH) {
                // The standard pulse length for pulse dialing is 60 milliseconds (ms) on and  
                // 40ms off for each pulse, with an inter-digit pause of 700ms between digits
                delay(35); 
                if (digitalRead(input_pulse)==LOW) { // If it is NOT the longer Hook down pulse (>100ms)
                  pulseCount++;
                  if (!dialing) { // Start dial cycle...
                    #ifdef DEBUG
                      Serial.println(F("Dialing started..."));
                    #endif
                    processNumber = false;
                    dialing = true;
                    nrsDialed = 0;
                    bankNr = -1;
                    myDFPlayer.stop(); // End dial tone...   
                  }
                }
              }
              dialingTimeout = millis(); // Keep resetting timer during dialing...
            }
          }
          lastGpioStatePulse = gpioStatePulse;

          // Time-out between pulse dialed numbers...
          if (pulseCounting && (millis() - debounceTimePulse) > 300) {
            pulseCounting = false;
            if (pulseCount>0) {
              #ifdef DEBUG
                Serial.print(F("Pulse Count: "));
                Serial.println(pulseCount);
              #endif
              nrsDialed++;
              #ifdef DEBUG
                Serial.print(F("Dial number ("));
                Serial.print(nrsDialed);
                Serial.print(F(") dialed: "));
                Serial.println(pulseCount);
              #endif

              if (bankNr<0) {
                bankNr = pulseCount;
                #ifdef DEBUG
                  Serial.println("bankNr: "+(String)bankNr);
                #endif
              }
              lastNumberDialed = pulseCount;
              #ifdef DEBUG
                Serial.println("lastNumberDialed: "+(String)lastNumberDialed);
              #endif
              pulseCount = 0;   
            }   
          }

        }
      }

      // Detecting if dialing phase has ended...
      if (dialing && ((millis() - dialingTimeout) > 2500)) {
        // Dial time out reached...
        #ifdef DEBUG
          Serial.println(F("Dialing finished..."));
        #endif
        processNumber = true;
        dialing = false;
      } 

      // Handling the audio if dialing phase has ended...
      if (processNumber) {
        processNumber = false;
        if (nrFolders>1) {
          if (nrsDialed==1)
            bankNr = 1; // Only one number dialed: use default bank 1...

          // Play WAV....
          #ifdef DEBUG
            Serial.println("Want to play bankNr "+(String)bankNr+" song "+(String)lastNumberDialed);
            Serial.println("Nr files in that folder is "+(String)nrFilesInFolder[bankNr-1]);
          #endif

          if (lastNumberDialed<=nrFilesInFolder[bankNr-1]) {
            digitalWrite(led_dial_play, HIGH); // Power off green LED...
            digitalWrite(led_playing, LOW);    // Turn the red LED on (HIGH=off)
            myDFPlayer.playFolder(bankNr, lastNumberDialed); // Play the song...
            playerActive = true;
          } else { // Sound file with this bank and file index does not exist...
            #ifdef DEBUG
              Serial.println("bankNr "+(String)bankNr+" song "+(String)lastNumberDialed+" does not exist...");
            #endif
            // Output busy tone in stead...
            myDFPlayer.play(2);
          }
          
        } else { // Config error: no folders...
          // Output busy tone in stead...
          myDFPlayer.play(2);
        }
      }
    } // END: if !playerActive
  } else { // END: if hookUp...
    digitalWrite(led_config, LOW); // Turn off Util/Config LED...
    playerActive = false;
    dialing = false;
  }
}

void printDetail(uint8_t type, int value) {
  switch (type) {
    case TimeOut:
      Serial.println(F("DFPlayer: Time Out!"));
      break;
    case WrongStack:
      Serial.println(F("DFPlayer: Stack Wrong!"));
      break;
    case DFPlayerCardInserted:
      Serial.println(F("DFPlayer: Card Inserted!"));
      break;
    case DFPlayerCardRemoved:
      Serial.println(F("DFPlayer: Card Removed!"));
      break;
    case DFPlayerCardOnline:
      Serial.println(F("DFPlayer: Card Online!"));
      break;
    case DFPlayerUSBInserted:
      Serial.println(F("DFPlayer: USB Inserted!"));
      break;
    case DFPlayerUSBRemoved:
      Serial.println(F("DFPlayer: USB Removed!"));
      break;
    case DFPlayerPlayFinished:
      Serial.println("DFPlayer: Number:"+(String)value+" Play Finished!");
      break;
    case DFPlayerError:
      switch (value) {
        case Busy:
          Serial.println(F("DFPlayerError: Card not found"));
          break;
        case Sleeping:
          Serial.println(F("DFPlayerError: Sleeping"));
          break;
        case SerialWrongStack:
          Serial.println(F("DFPlayerError: Get Wrong Stack"));
          break;
        case CheckSumNotMatch:
          Serial.println(F("DFPlayerError: Check Sum Not Match"));
          break;
        case FileIndexOut:
          Serial.println(F("DFPlayerError: File Index Out of Bound"));
          break;
        case FileMismatch:
          Serial.println(F("DFPlayerError: Cannot Find File"));
          break;
        case Advertise:
          Serial.println(F("DFPlayerError: In Advertise"));
          break;
        default:
          break;
      }
      break;
    default:
      break;
  }
}
